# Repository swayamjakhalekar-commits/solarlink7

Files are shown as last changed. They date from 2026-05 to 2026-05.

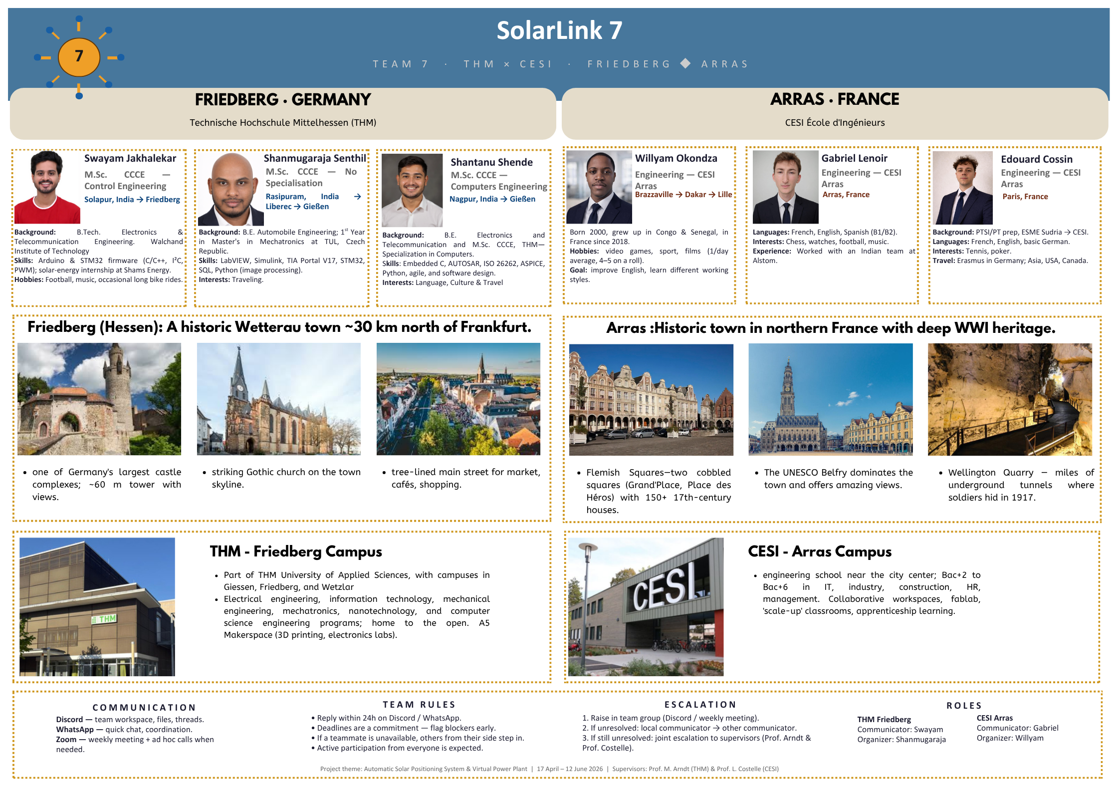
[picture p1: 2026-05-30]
Team and Project/SolarLink7-Poster.png

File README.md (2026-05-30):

# SolarLink7

Automated solar-tracker prototypes at **THM Friedberg (DE)** and **CESI Arras (FR)**,
networked over MQTT into a shared **virtual power plant (VPP)** dashboard. Both sites run
identical prototypes that can be monitored and remote-controlled across one broker.
Built for **COIL 2026 · Course M1202 (Project Management)**.

## Status
Prototypes built and demonstrated at both sites during the project week (27–29 May 2026).
Cross-site MQTT control and the Node-RED VPP dashboard are functioning.
Final presentation: **12 June 2026**.

## Team
| Site | Members |
|---|---|
| THM Friedberg | Swayam Jakhalekar (communicator), Shanmugaraja Senthil (organizer), Shantanu Shende |
| CESI Arras | Gabriel Lenoir (communicator), Willyam Okondza (organizer), Edouard Cossin |
| Supervisors | Prof. Dr. M. Arndt (THM), Prof. L. Costelle (CESI) |

## What it does
Each node reads panel voltage/current via an INA219 sensor, positions the panel with two
servos (automatic maximum-power search, or manual override from the dashboard), shows live values
on a local LCD (THM), and publishes telemetry over MQTT. The Node-RED dashboard shows both
sites side by side and can command either one — that two-site, remote-controllable view is
the VPP demo.

## Repository layout
```
SolarLink7/
├── Arduino Codes/
│   ├── Team7_Friedberg_FinalCode/   # THM firmware
│   ├── Team7_Arras_FinalCode/       # CESI firmware
│   ├── Servos_ZeroPos/              # servo zero/home reference helper
│   └── Servos_MovIndetifier/        # servo direction-of-motion helper
├── 3D_PrintingParts/                # STL parts (base, arm, panel supports, ...)
├── Electronics/                     # Circuit Wiring.png (INA219 + Arduino)
├── Node-Red/                        # Team7_FinalFlow.json + MQTT/Node-RED setup PDF
├── Project Planning and Report/     # WBS, Gantt, competence analysis (PDF)
├── Team and Project/                # brief, poster, team roles/rules/comms plan
├── Measurement/                     # I-V curves, INA219 logs (to be added)
├── Media/                           # photos/video — see Google Drive (not committed)
└── Reflections/                     # weekly reflection journals (to be added)
```

## How tracking works
Tracking is a **two-axis maximum-power search** — measurement-based, not astronomical and
not LDR-based. The panel physically moves and the INA219 power reading (voltage × current)
decides where it settles.

- **Startup:** both servos home, then a full sweep — horizontal 0–180° in 5° steps, then
  vertical, settling 700 ms at each step and recording power. The panel moves to the angle
  that produced the most power. Horizontal is searched first, then vertical.
- **Auto mode:** every 2 minutes the node re-scans only a narrow window around the current
  best (horizontal ±30°, vertical ±20°) rather than a full sweep, so it follows the sun's
  drift without a costly full search each cycle.
- **Manual mode:** a dashboard `control/angle-h|v` command switches the node to manual and
  drives to the requested angle; `control/mode` toggles auto/manual.

Both sites run the identical algorithm; the THM node additionally shows live values on a
16×2 I2C LCD.

## System & MQTT
- **Broker:** `broker.hivemq.com:1883` (public, no auth)
- **Topic base:** `cesithmcoil2025/Team7/<SITE>/` where `<SITE>` is `Friedberg` or `Arras`
- **Telemetry:** `panel-voltage`, `panel-current`, `panel-power`, `position/angle-h`,
  `position/angle-v`, `status`
- **Control:** `control/mode`, `control/angle-h`, `control/angle-v`

The dashboard subscribes to each site's `…/#` wildcard, splits the stream per site, and
routes each field to a widget; control widgets publish back on the `control/...` topics.
See `Node-Red/` for the flow export and setup walkthrough.

## Stack
- **Hardware:** Arduino UNO R4 WiFi · INA219 · 2× SG90 servos · 16×2 I2C LCD (THM) · panel 6.4 V / 360 mA
- **Tracking:** two-axis maximum-power search (INA219 power feedback) — no LDRs, no lat/lon
- **Dashboard:** Node-RED
- **CAD:** TinkerCAD → STL

## Links
- Google Drive (deliverables, media): _add link_
- Trello (task board): _add link_

## License / use
Coursework artifact for M1202. Not for redistribution outside the course.

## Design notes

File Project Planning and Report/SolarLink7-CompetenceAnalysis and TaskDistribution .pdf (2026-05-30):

Member | Site | Role | Project Management | CAD / 3D Design | 3D Printing | Hardware Assembly | Firmware (Arduino) | MQTT / IoT | Node-RED / Dashboard | Documentaion
Swayam Jakhalekar | THM | Communicator | X | | | | X | X | X | X
Shanmugaraja Senthil | THM | Organiser | • | X | | X | | | | X
Shantanu Shende | THM | Member | | | X | • | X | X | X | •
Gabriel Lenoir | CESI | Communicator | X | | | | • | X | X | X
Willyam Okondza | CESI | Organiser | • | X | • | X | • | | | •
Edouard Cossin | CESI | Member | | | X | X | | | | X

Legend:

SolarLink 7 — Team Competence Analysis

Competence areas mapped against assigned project workstreams. X = lead competence; • = supporting competence.

X = lead competence • • = supporting competence • blank = not engaged on this workstream

WBS ID | Task | Type | THM Owner | CESI Owner | Notes
1.1 | Planning document & baseline | Cross-site coordination | Swayam | Gabriel | Communicators jointly own document
1.2 | Weekly steering & minutes | Cross-site coordination | Swayam | Gabriel | Thursday 12:00 CET, Google Meet
1.3 | Risk & issue log | Cross-site coordination | Swayam | Gabriel | Living document, GitHub-tracked
1.4 | Report — technical sections | Joint | Shanmugaraja | Edouard | Firmware, electronics, mechanical
1.5 | Report — PM sections | Joint | Swayam | Gabriel | WBS/Gantt retrospective, lessons learned
1.6 | Report — analysis & conclusions | Joint | All THM | All CESI | Whole-team contribution
1.7 | Final report assembly & review | Cross-site coordination | Swayam | Gabriel | Communicators integrate sections
2.1 | Static panel holder — TinkerCAD design | Joint | Shanmugaraja | Willyam | Lead designer: Willyam; handover to THM via GitHub
2.2 | Print static holder — THM | Site-local | Shantanu | — | Local print at THM open.A5 Makerspace
2.3 | Print static holder — CESI | Site-local | — | Edouard | Local print at CESI facility
2.4 | SPP CAD design | Joint | Shanmugaraja | Willyam | Lead designer: Willyam
2.5 | Print SPP brackets — THM | Site-local | Shantanu | — | Local print at THM
2.6 | Print SPP brackets — CESI | Site-local | — | Edouard | Local print at CESI
2.7 | Servo mounting & calibration | Joint | Shanmugaraja | Willyam | Project week
3.1 | BOM & wiring schematic | Joint | Shanmugaraja | Willyam | Single shared schematic for both sites
3.2 | Build & bring-up — THM | Site-local | Shanmugaraja | — | Identical kit, parallel build
3.3 | Build & bring-up — CESI | Site-local | — | Willyam | Identical kit, parallel build
3.4 | INA219 calibration | Joint | Swayam | Gabriel | Cross-validate with multimeter
3.5 | Sensor + servo firmware | Joint | Swayam | Gabriel | Lead: Swayam; handover to Gabriel
3.6 | Tracking algorithm | Joint | Swayam | Gabriel | Lead: Swayam; time-based, NTP + sun position
3.7 | Local LCD display | Joint | Shanmugaraja | Willyam | Optional; voltage/current/power output
4.1 | MQTT topic schema (cesithmcoil2025/) | Joint | Swayam | Gabriel | Co-designed by communicators
4.2 | MQTT client on Arduino | Joint | Shantanu | Willyam | Setup lead: Shantanu; CESI support
4.3 | Node-RED ingest flow | Joint | Shantanu | Edouard | Setup lead: Shantanu
4.4 | Node-RED VPP dashboard | Joint | Shantanu | Edouard | Setup lead: Shantanu
4.5 | Remote-command handler | Joint | Shantanu | Edouard | End-to-end bidirectional control
5.1 | Site-local end-to-end test | Site-local | All THM | All CESI | Each site validates own prototype
5.2 | Cross-site MQTT test | Cross-site coordination | All THM | All CESI | Both sites publish simultaneously
5.3 | IV-curve measurements | Site-local | All THM | All CESI | Multimeter-based; 27 May project week
5.4 | MPP + optimal load resistor | Site-local | All THM | All CESI | Derived from IV-curve data
5.5 | 30-min energy measurement | Site-local | All THM | All CESI | Fixed tilt, optimal load
5.6 | Project week integration | Cross-site coordination | All THM | All CESI | 27–29 May, joint working window

## SolarLink 7 — Distribution of Tasks Between Locations

Mapping of project tasks to ownership type and location. Site-local = single-site task; Joint = co-owned cross-site; Cross-site coordination = communicator-led bridging task.

Site-local tasks | 10
Joint tasks | 16
Cross-site coordination tasks | 6
Total tasks | 32

## SUMMARY

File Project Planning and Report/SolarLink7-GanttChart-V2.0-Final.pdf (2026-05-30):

Task | Assigned (THM) Assigned (CESI) Progress (%) | Start | End | Status | Days Off

26-04

27-04

28-04

29-04

30-04

01-05

02-05

03-05

04-05

05-05

06-05

07-05

08-05

09-05

10-05

11-05

12-05

13-05

14-05

15-05

16-05

17-05

18-05

19-05

20-05

21-05

22-05

23-05

24-05

25-05

26-05

27-05

28-05

29-05

30-05

31-05

01-06

02-06

03-06

04-06

05-06

06-06

07-06

08-06

09-06

10-06

11-06

12-06

Project Management | | | 0
Planning document & baseline | THM Group | CESI Group | 90% | 2026-04-26 | 2026-05-18 | In Progress | 0
Weekly steering & minutes (Every week group meeting) | Swayam | Gabriel | 30% | 2026-04-29 | 2026-06-12 | In Progress | 0
Risk & issue log | THM Group | CESI Group | 5% | 2026-05-08 | 2026-06-12 | In Progress | 0
Report — technical sections | Shanmugaraja | Edouard | 0% | 2026-05-30 | 2026-06-05 | Upcoming | 0
Report — PM sections | Swayam | Gabriel | 0% | 2026-05-30 | 2026-06-05 | Upcoming | 0
Report — analysis & conclusions | THM Group | CESI Group | 0% | 2026-06-01 | 2026-06-08 | Upcoming | 0
Final report assembly & review | Swayam | Gabriel | 0% | 2026-06-09 | 2026-06-11 | Upcoming | 0
Mechanical Subsystem | | | 0
Static panel holder — TinkerCAD design (joint) | Shanmugaraja | Willyam | 0% | 2026-05-21 | 2026-05-21 | Upcoming | 0
Print static holder — THM | Shantanu | | 0% | 2026-05-21 | 2026-05-21 | Upcoming | 0
Print static holder — CESI | | Edouard | 0% | 2026-05-21 | 2026-05-21 | Upcoming | 0
SPP CAD design (joint) | Shanmugaraja | Willyam | 0% | 2026-05-22 | 2026-05-22 | Upcoming | 0
Print SPP brackets — THM | Shantanu | | 0% | 2026-05-22 | 2026-05-22 | Upcoming | 0
Print SPP brackets — CESI | | Edouard | 0% | 2026-05-22 | 2026-05-22 | Upcoming | 0
Servo mounting & calibration | Shanmugaraja | Willyam | 0% | 2026-05-23 | 2026-05-23 | Upcoming | 0
Electronics & Firmware | | | 0
BOM & wiring schematic | Shanmugaraja | Willyam | 0% | 2026-05-24 | 2026-05-25 | Upcoming | 0
Build & bring-up — THM | Shanmugaraja | | 0% | 2026-05-26 | 2026-05-26 | Upcoming | 0
Build & bring-up — CESI | | Willyam | 0% | 2026-05-26 | 2026-05-26 | Upcoming | 0
INA219 calibration | Swayam | Gabriel | 0% | 2026-05-27 | 2026-05-27 | Upcoming | 0
Sensor + servo | Swayam | Gabriel | 0% | 2026-05-26 | 2026-05-26 | Upcoming | 0
Tracking algorithm | Swayam | Gabriel | 0% | 2026-05-27 | 2026-05-27 | Upcoming | 0
Local LCD display (voltage/current/power output) | Shanmugaraja | Willyam | 0% | 2026-05-27 | 2026-05-27 | Upcoming | 0
MQTT & Dashboard | | | 0
Topic schema under cesithmcoil2025/ | Swayam | Gabriel | 0% | 2026-05-14 | 2026-05-17 | In Progress | 0
MQTT client on Arduino | Shantanu | Willyam | 0% | 2026-05-17 | 2026-05-20 | Upcoming | 0
Node-RED ingest flow | Shantanu | Edouard | 0% | 2026-05-27 | 2026-05-27 | Upcoming | 0
Node-RED VPP dashboard | Shantanu | Edouard | 0% | 2026-05-28 | 2026-05-28 | Upcoming | 0
Remote-command handler | Shantanu | Edouard | 0% | 2026-05-28 | 2026-05-29 | Upcoming | 0
Integration, Test & Deliverables | | | 0
Site-local end-to-end test | THM Group | CESI Group | 0% | 2026-05-29 | 2026-05-29 | Upcoming | 0
Cross-site MQTT test | THM Group | CESI Group | 0% | 2026-05-29 | 2026-05-29 | Upcoming | 0
IV-curve measurements | THM Group | CESI Group | 0% | 2026-05-27 | 2026-05-27 | Upcoming | 0
MPP + optimal load resistor derivation | THM Group | CESI Group | 0% | 2026-05-27 | 2026-05-27 | Upcoming | 0
30-min energy measurement | THM Group | CESI Group | 0% | 2026-05-27 | 2026-05-27 | Upcoming | 0
Project week integration | THM Group | CESI Group | 0% | 2026-05-25 | 2026-05-29 | Upcoming | 0

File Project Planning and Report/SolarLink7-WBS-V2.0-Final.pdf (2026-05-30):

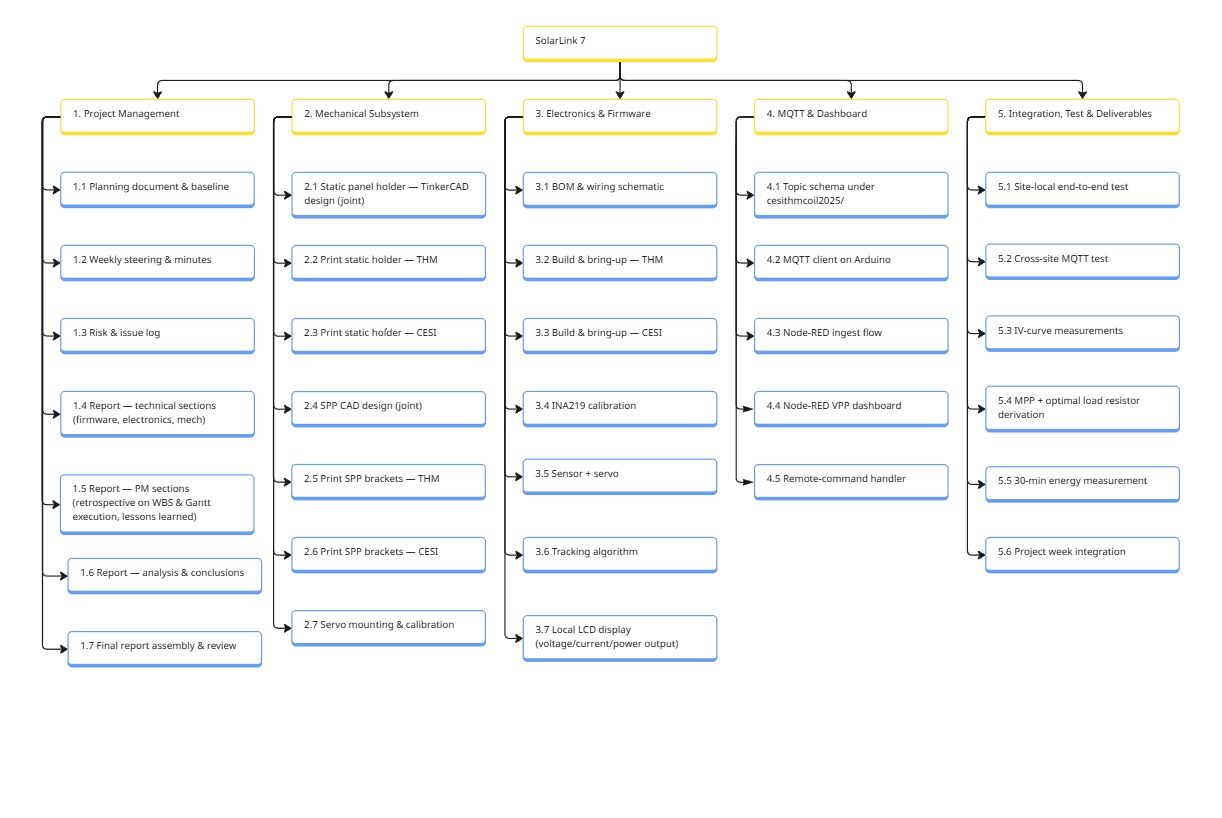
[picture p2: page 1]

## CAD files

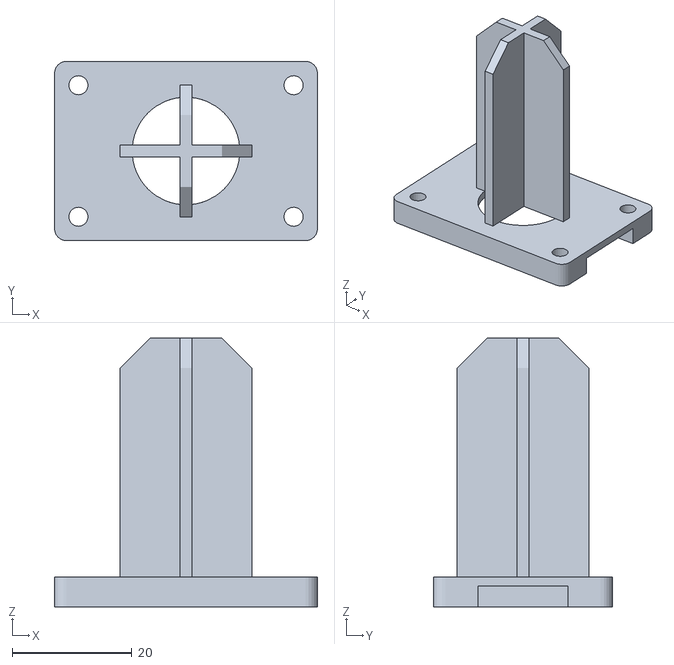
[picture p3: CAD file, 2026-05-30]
3D_PrintingParts/LDR.stl
44.0 x 30.0 x 45.0

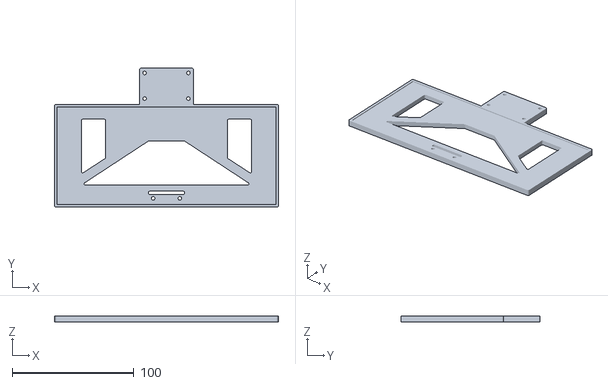
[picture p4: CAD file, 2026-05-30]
3D_PrintingParts/PanelSupport(L).stl
184.0 x 114.0 x 5.00

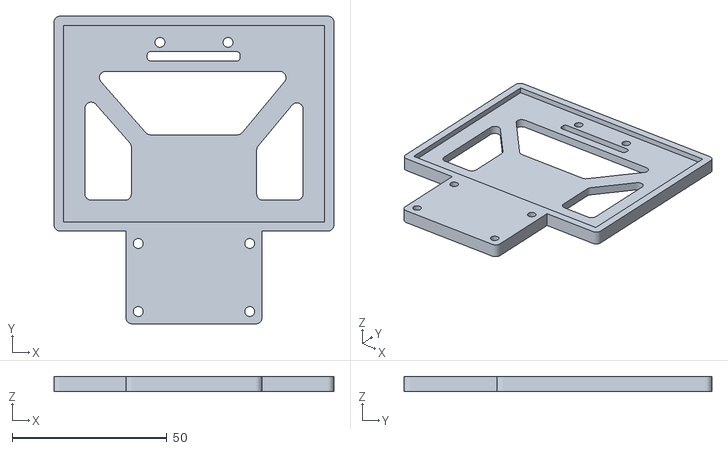
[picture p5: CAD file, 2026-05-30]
3D_PrintingParts/PanelSupport(S).stl
90.5 x 99.5 x 5.00

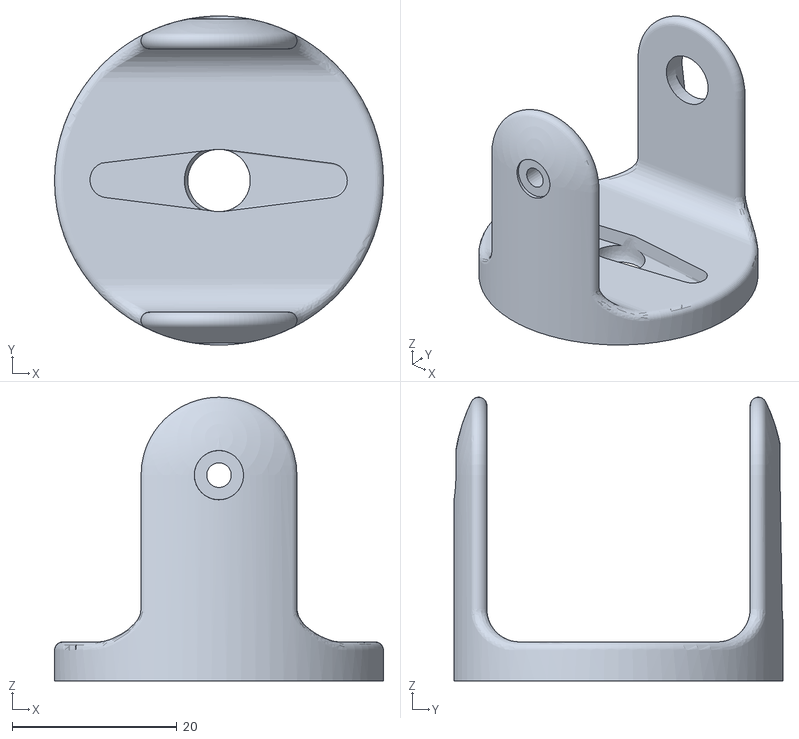
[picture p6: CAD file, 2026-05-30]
3D_PrintingParts/Middle2.0.stl
40.0 x 40.0 x 34.5

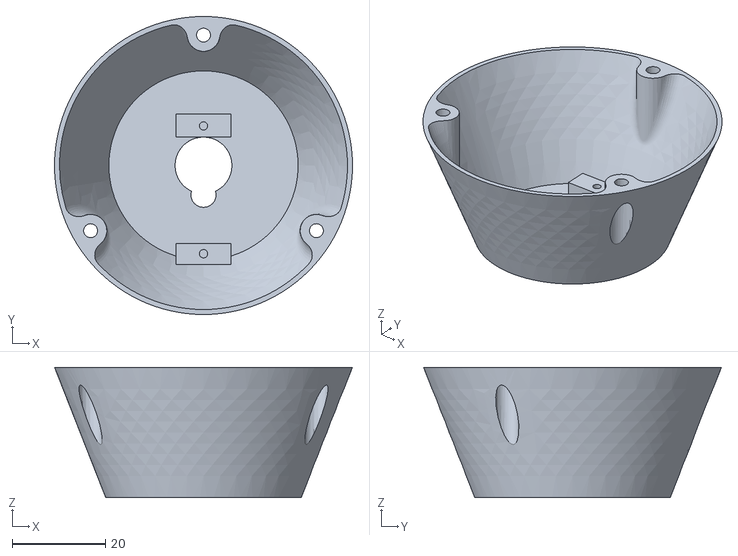
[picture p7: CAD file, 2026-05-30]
3D_PrintingParts/OrgBase.stl
64.0 x 64.0 x 28.0

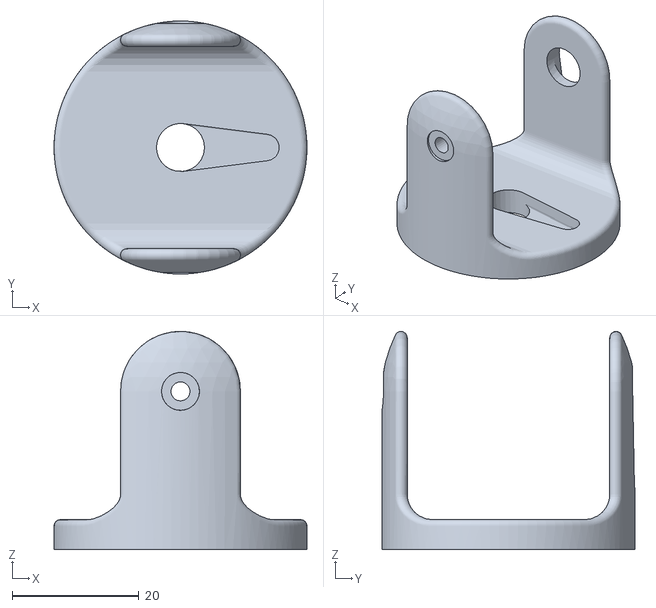
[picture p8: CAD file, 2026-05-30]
3D_PrintingParts/OrgMiddle.stl
40.0 x 40.0 x 34.5

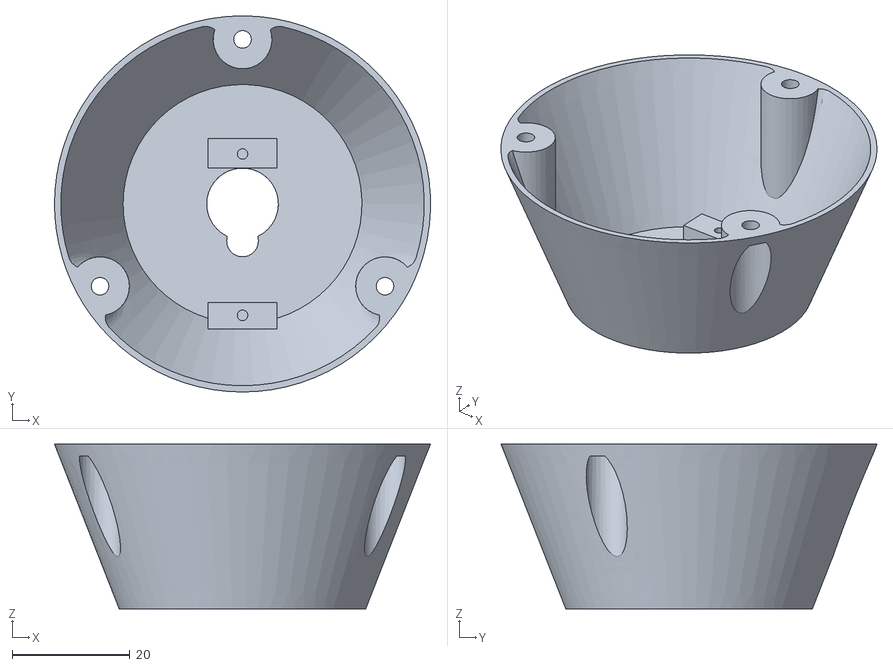
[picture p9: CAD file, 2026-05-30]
3D_PrintingParts/Base2.0.stl
64.0 x 64.0 x 28.0

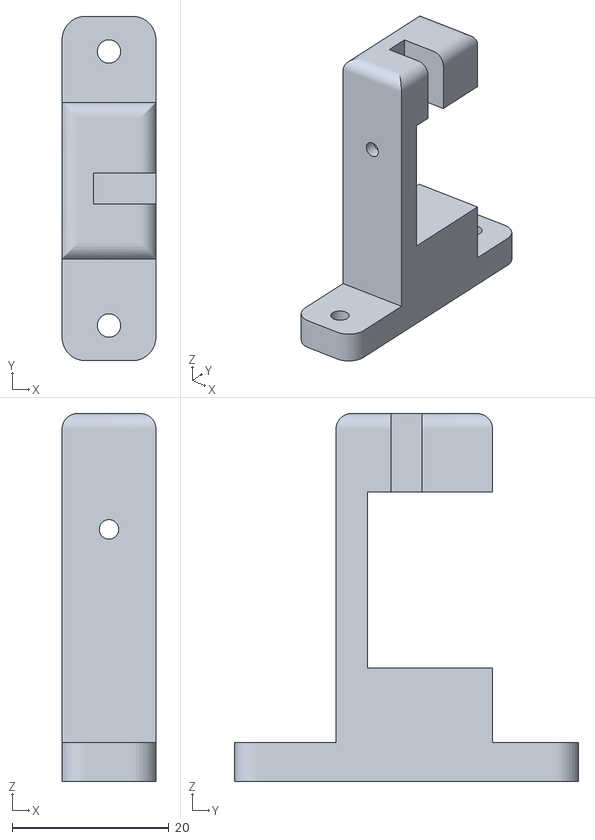
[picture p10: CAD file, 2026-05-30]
3D_PrintingParts/ActualArm.stl
12.0 x 44.0 x 47.0

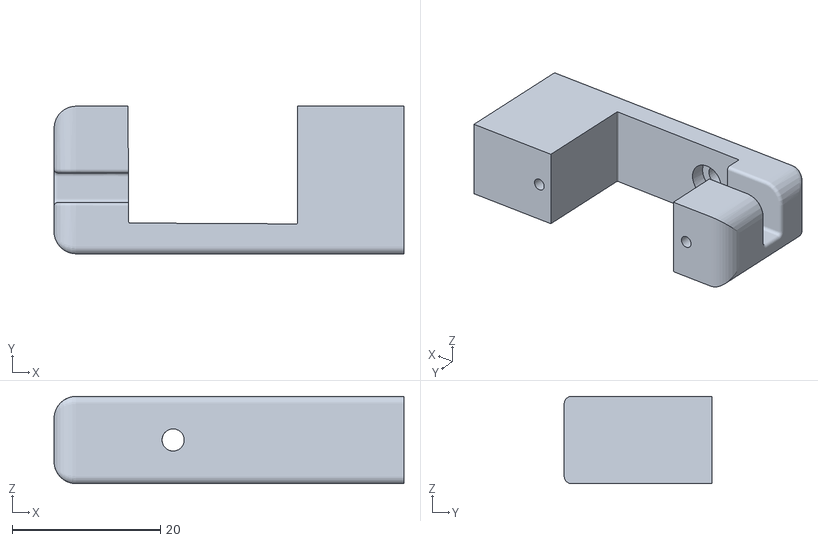
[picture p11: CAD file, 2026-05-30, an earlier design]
3D_PrintingParts/OldArm.stl
47.3 x 19.9 x 11.8

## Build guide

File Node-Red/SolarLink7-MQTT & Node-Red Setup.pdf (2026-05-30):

MQTT and Node-Red Setups Document

Project: Connected Solar Tracker using IoT (MQTT + Node-RED) Team: SolarLink7 (THM / ARRAS)

### 1. Software Used

Software | Purpose | Link
MQTT Explorer | Monitoring MQTT messages | https://mqtt-explorer.com/
Node js | To install Node-Red to work | https://nodejs.org/en/download
Node - Red | Dashboard and Visualization | Node-RED

### 2. MQTT Configuration

Click on (+) and add new connections with following parameters.
Name: Hive
Host: Broker: broker.hivemq.com
Port: 1883

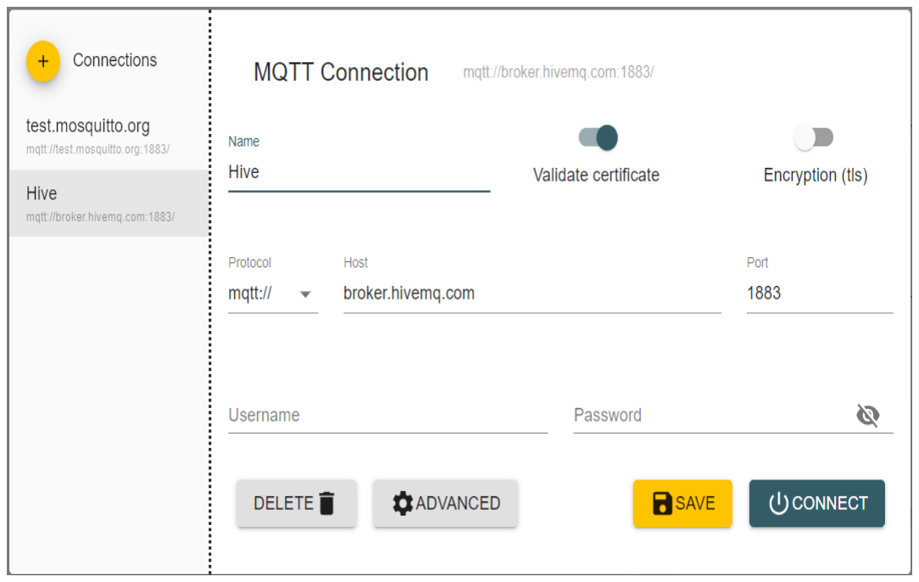
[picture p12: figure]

Then click on Advanced

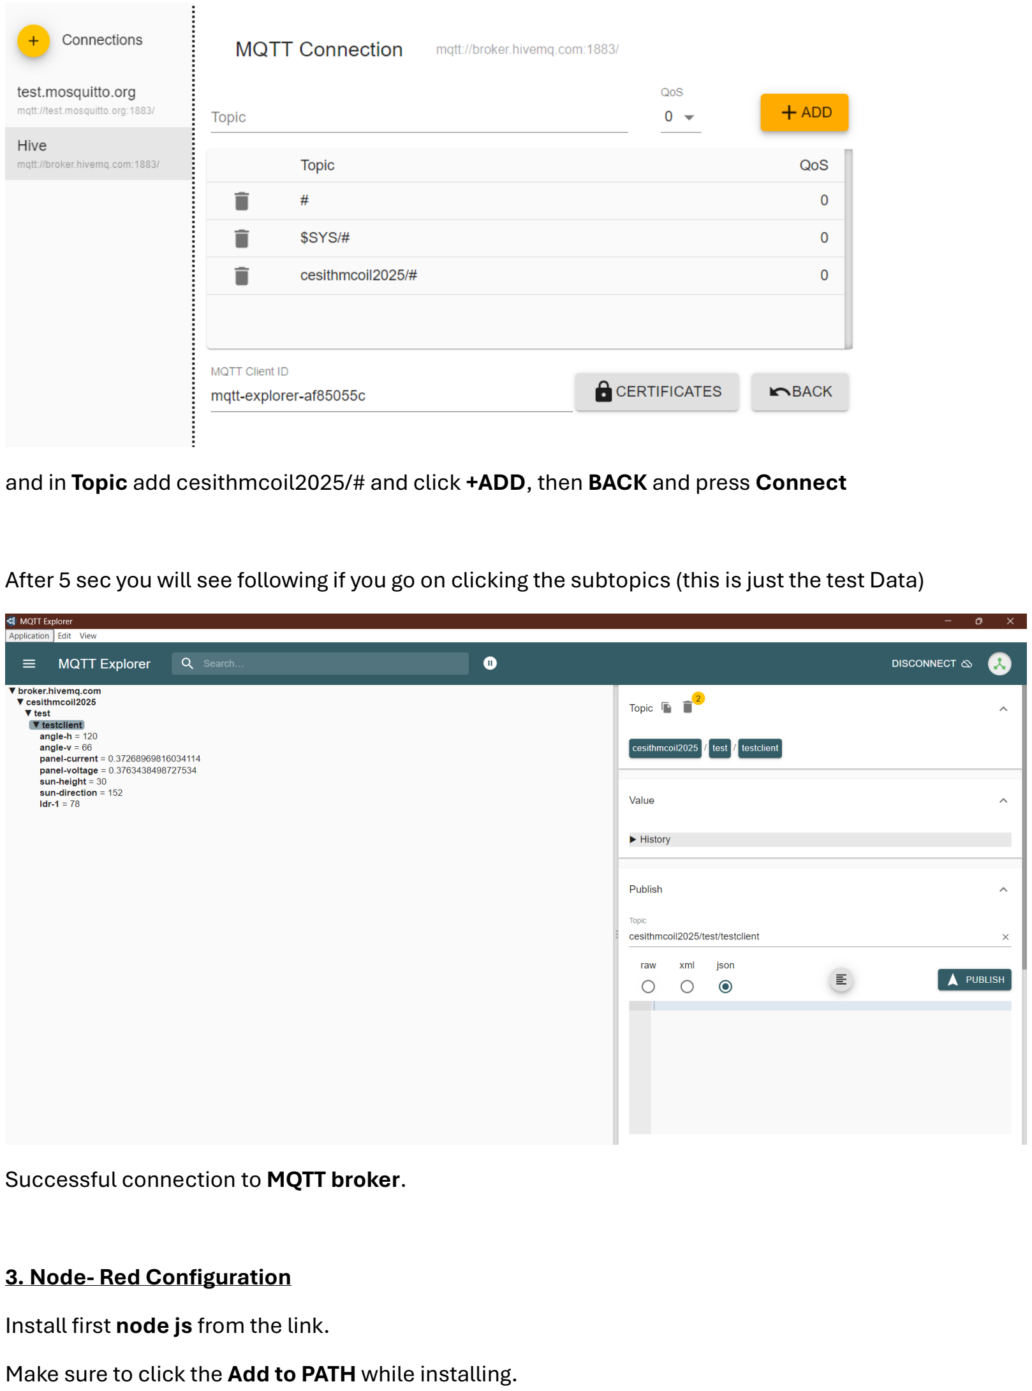
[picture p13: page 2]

and in Topic add cesithmcoil2025/# and click +ADD, then BACK and press Connect

After 5 sec you will see following if you go on clicking the subtopics (this is just the test Data)

Successful connection to MQTT broker.

### 3. Node- Red Configuration

Install first node js from the link.
Make sure to click the Add to PATH while installing.

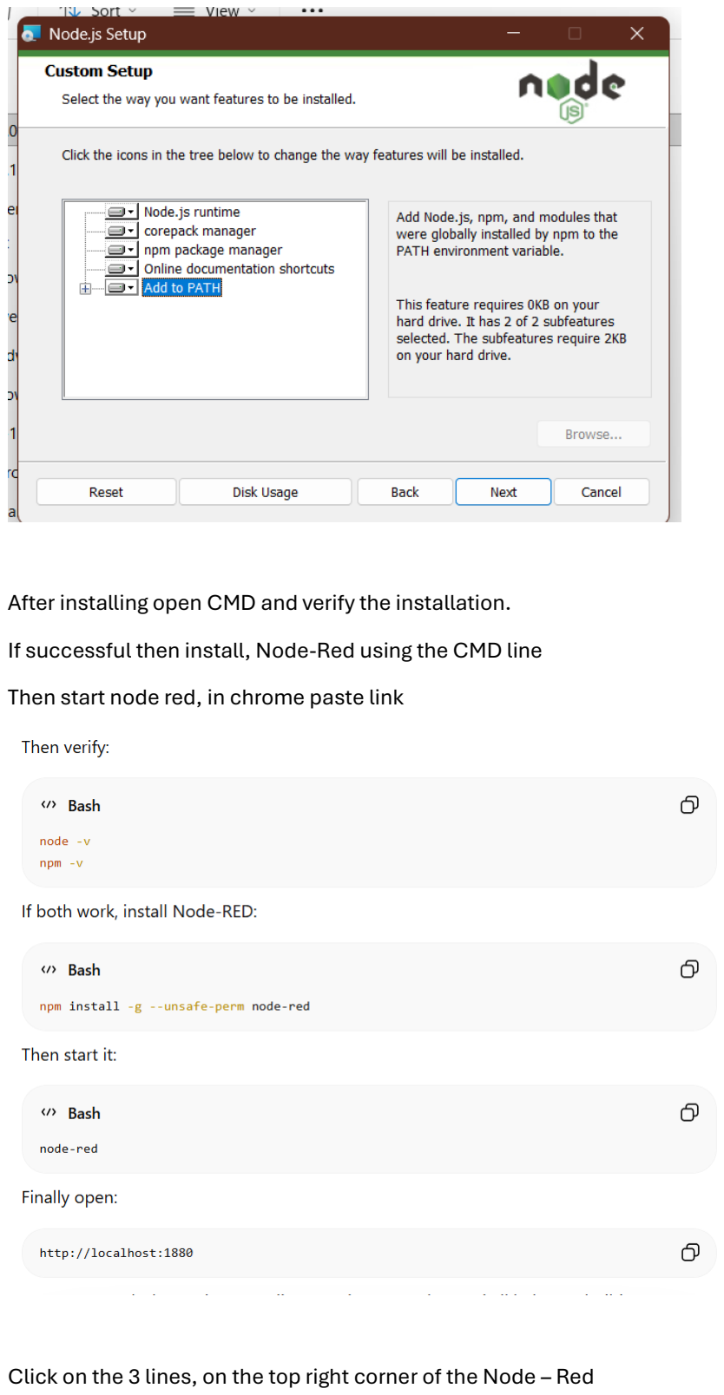
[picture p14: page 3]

After installing open CMD and verify the installation. If successful then install, Node-Red using the CMD line Then start node red, in chrome paste link

Click on the 3 lines, on the top right corner of the Node – Red

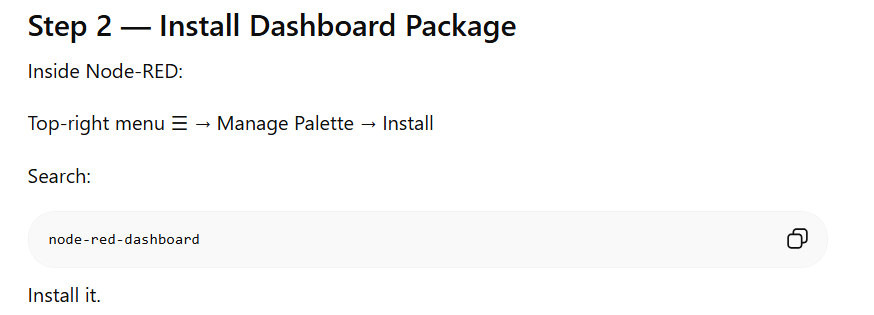
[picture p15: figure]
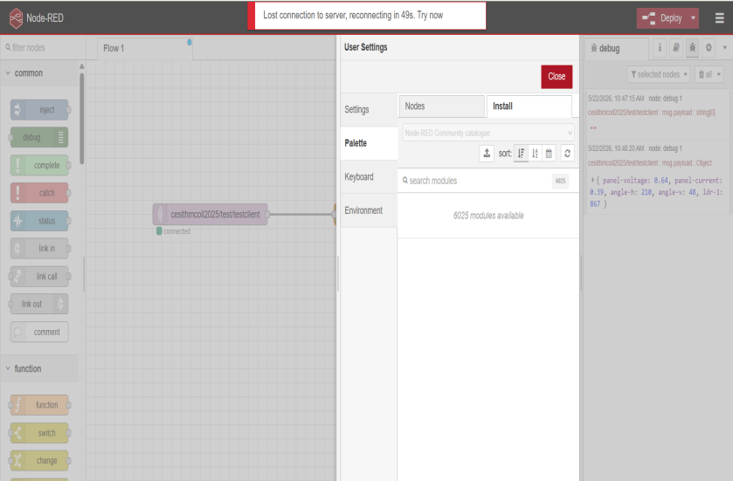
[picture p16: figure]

Then build Flow for the Team .

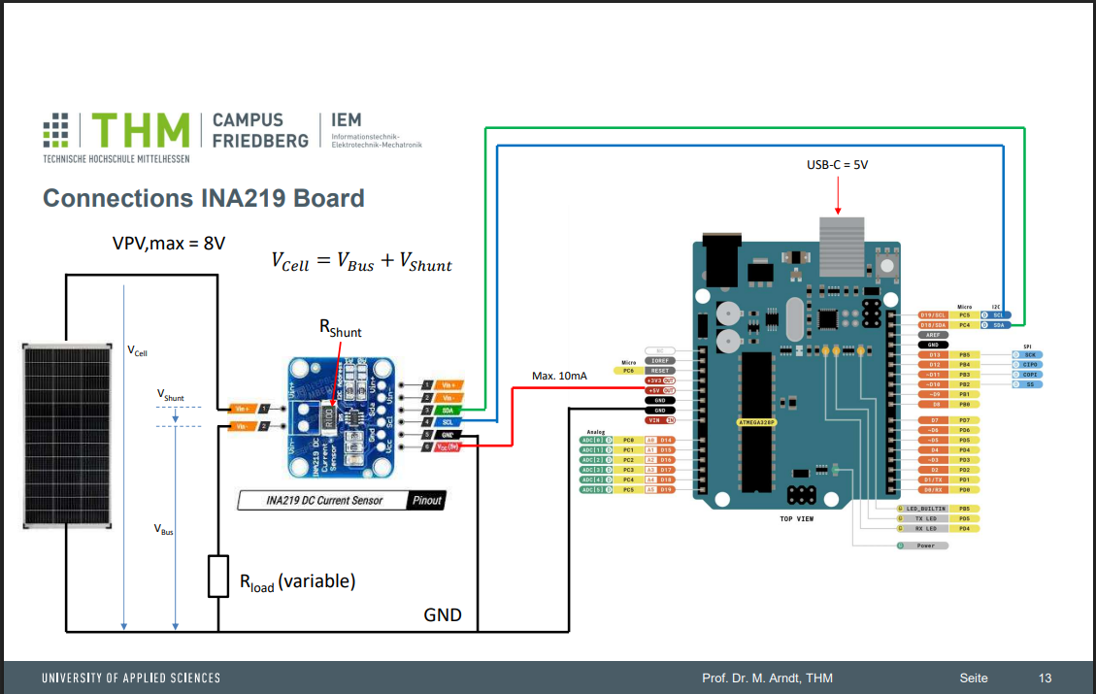
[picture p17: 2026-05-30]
Electronics/Circuit Wiring.png

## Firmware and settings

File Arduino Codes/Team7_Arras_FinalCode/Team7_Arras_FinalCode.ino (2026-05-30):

// ======================================================
// TEAM7 FINAL SOLAR TRACKER
// ARRAS FINAL VERSION
// ======================================================

#include <Wire.h>
#include <WiFiS3.h>
#include <PubSubClient.h>
#include <Adafruit_INA219.h>
#include <Servo.h>

// ======================================================
// WIFI
// ======================================================

char ssid[] = //"YOUR SSID";
char pass[] = //"YOUR PASSWORD";

// ======================================================
// MQTT
// ======================================================

const char* mqtt_server =
"broker.hivemq.com";

WiFiClient wifiClient;

PubSubClient client(wifiClient);

// ======================================================
// COMPONENTS
// ======================================================

Adafruit_INA219 ina219;

Servo servoH;
Servo servoV;

// ======================================================
// SERVO PINS
// ======================================================

const int SERVO_H_PIN = 9;
const int SERVO_V_PIN = 10;

// ======================================================
// SERVO SETTINGS
// ======================================================

const int CENTER_V = 90;

// smoother movement

const int STEP_DELAY_MIN = 15;
const int STEP_DELAY_MAX = 45;

const int EASE_FRACTION  = 35;

const int SETTLE = 700;

// ======================================================
// HOMING SETTINGS
// ======================================================

// smoother homing

const int HOME_STEP_DEG = 5;
const int HOME_STEP_MS  = 50;

// ======================================================
// SCAN SETTINGS
// ======================================================

// smoother scanning

const int H_SCAN_STEP = 5;
const int V_SCAN_STEP = 5;

const int H_RESCAN_MARGIN = 30;
const int V_RESCAN_MARGIN = 20;

const unsigned long SCAN_INTERVAL =
120000UL;

unsigned long lastScanTime = 0;

// ======================================================
// POSITION VARIABLES
// ======================================================

int currentH = 90;

// INTERNAL RANGE = -50 → +50

int currentV = 0;

// ======================================================
// POWER VARIABLES
// ======================================================

float voltage    = 0;
float current_mA = 0;
float power_mW   = 0;

// ======================================================
// MODE
// ======================================================

bool manualMode = false;

// ======================================================
// MQTT TOPICS
// ======================================================

const char* topic_h_angle =
"cesithmcoil2025/Team7/Arras/position/angle-h";

const char* topic_v_angle =
"cesithmcoil2025/Team7/Arras/position/angle-v";

const char* topic_voltage =
"cesithmcoil2025/Team7/Arras/panel-voltage";

const char* topic_current =
"cesithmcoil2025/Team7/Arras/panel-current";

const char* topic_power =
"cesithmcoil2025/Team7/Arras/panel-power";

const char* topic_status =
"cesithmcoil2025/Team7/Arras/status";

const char* control_h =
"cesithmcoil2025/Team7/Arras/control/angle-h";

const char* control_v =
"cesithmcoil2025/Team7/Arras/control/angle-v";

const char* control_mode =
"cesithmcoil2025/Team7/Arras/control/mode";

// ======================================================
// EASING
// ======================================================

int easeDelay(int moved, int total) {

  if (total == 0)
    return STEP_DELAY_MIN;

  int easeSteps =
    max(1,
    (total * EASE_FRACTION) / 100);

  int remaining = total - moved;

  if (moved < easeSteps) {

    return STEP_DELAY_MAX -
      ((STEP_DELAY_MAX -
      STEP_DELAY_MIN)
      * moved / easeSteps);
  }

  if (remaining < easeSteps) {

    return STEP_DELAY_MIN +
      ((STEP_DELAY_MAX -
      STEP_DELAY_MIN)
      * (easeSteps - remaining)
      / easeSteps);
  }

  return STEP_DELAY_MIN;
}

// ======================================================
// MOVE HORIZONTAL
// ======================================================

void moveH(int target) {

  target = constrain(target, 0, 180);

  if (target == currentH)
    return;

  int total =
    abs(target - currentH);

  int step =
    (target > currentH)
    ? 1 : -1;

  int moved = 0;

  while (currentH != target) {

    currentH += step;

    servoH.write(currentH);

    delay(
      easeDelay(moved++, total)
    );
  }
}

// ======================================================
// MOVE VERTICAL
// ======================================================

void moveV(int target) {

  target = constrain(target, -50, 50);

  if (target == currentV)
    return;

  int total =
    abs(target - currentV);

  int step =
    (target > currentV)
    ? 1 : -1;

  int moved = 0;

  while (currentV != target) {

    currentV += step;

    servoV.write(
      CENTER_V + currentV
    );

    delay(
      easeDelay(moved++, total)
    );
  }
}

// ======================================================
// SAFE HOME HORIZONTAL
// ======================================================

void safeHomeH() {

  Serial.println("Homing Horizontal Servo...");

  servoH.write(90);

  delay(500);

  for (int h = 90; h >= 0; h -= HOME_STEP_DEG) {

    servoH.write(h);

    Serial.print("H Position: ");
    Serial.println(h);

    delay(HOME_STEP_MS);
  }

  servoH.write(0);

  delay(300);

  currentH = 0;

  Serial.println("Horizontal Homing Complete");

  delay(700);
}

// ======================================================
// SAFE HOME VERTICAL
// ======================================================

void safeHomeV() {

  Serial.println("Homing Vertical Servo...");

  // stabilize at center first

  servoV.write(CENTER_V);

  delay(700);

  // smooth downward sweep

  for (int v = 0; v >= -50; v -= HOME_STEP_DEG) {

    servoV.write(CENTER_V + v);

    Serial.print("V Position: ");
    Serial.println(v + 50);

    delay(HOME_STEP_MS);
  }

  servoV.write(CENTER_V - 50);

  delay(300);

  currentV = -50;

  Serial.println("Vertical Homing Complete");

  delay(700);
}

// ======================================================
// POWER MEASUREMENT
// ======================================================

void measurePower() {

  voltage =
    ina219.getBusVoltage_V();

  current_mA =
    ina219.getCurrent_mA();

  power_mW =
    voltage * current_mA;
}

// ======================================================
// SERIAL MONITOR UPDATE
// ======================================================

void serialMonitorUpdate() {

  Serial.println("======================");

  Serial.print("MODE: ");

  Serial.println(
    manualMode ?
    "MANUAL" :
    "AUTO"
  );

  Serial.print("H-Angle: ");
  Serial.println(currentH);

  Serial.print("V-Angle: ");
  Serial.println(currentV + 50);

  Serial.print("Voltage: ");
  Serial.print(voltage);
  Serial.println(" V");

  Serial.print("Current: ");
  Serial.print(current_mA);
  Serial.println(" mA");

  Serial.print("Power: ");
  Serial.print(power_mW);
  Serial.println(" mW");

  Serial.println("======================");
}

// ======================================================
// MQTT PUBLISH
// ======================================================

void publishData() {

  client.publish(
    topic_h_angle,
    String(currentH).c_str()
  );

  client.publish(
    topic_v_angle,
    String(currentV + 50).c_str()
  );

  client.publish(
    topic_voltage,
    String(voltage, 2).c_str()
  );

  client.publish(
    topic_current,
    String(current_mA, 2).c_str()
  );

  client.publish(
    topic_power,
    String(power_mW, 2).c_str()
  );

  client.publish(
    topic_status,
    manualMode ?
    "MANUAL MODE" :
    "AUTO MODE"
  );

  serialMonitorUpdate();
}

// ======================================================
// WIFI CONNECTION (DHCP FIXED)
// ======================================================

void connectWiFi() {

  Serial.println("Connecting to WiFi...");

  WiFi.begin(ssid, pass);

  unsigned long start = millis();

  while (WiFi.status() != WL_CONNECTED) {

    delay(500);

    Serial.print(".");

    if (millis() - start > 15000) {

      Serial.println("\nRetrying WiFi...");

      WiFi.disconnect();

      delay(1000);

      WiFi.begin(ssid, pass);

      start = millis();
    }
  }

  while (WiFi.localIP() == IPAddress(0,0,0,0)) {

    Serial.println("Waiting for DHCP...");

    delay(500);
  }

  Serial.println("\nWiFi Connected");

  Serial.print("IP Address: ");
  Serial.println(WiFi.localIP());

  Serial.print("Signal Strength: ");
  Serial.println(WiFi.RSSI());
}

// ======================================================
// MQTT CALLBACK
// ======================================================

void callback(
  char* topic,
  byte* payload,
  unsigned int length
) {

  String message = "";

  for (
    unsigned int i = 0;
    i < length;
    i++
  ) {

    message += (char)payload[i];
  }

  Serial.print("MQTT Message [");
  Serial.print(topic);
  Serial.print("]: ");
  Serial.println(message);

  // MODE

  if (String(topic) == control_mode) {

    if (message == "AUTO")
      manualMode = false;

    if (message == "MANUAL")
      manualMode = true;
  }

  // HORIZONTAL

  if (String(topic) == control_h) {

    manualMode = true;

    moveH(message.toInt());
  }

  // VERTICAL

  if (String(topic) == control_v) {

    manualMode = true;

    int dashboardValue =
      message.toInt();

    int internalAngle =
      dashboardValue - 50;

    moveV(internalAngle);
  }
}

// ======================================================
// MQTT CONNECT
// ======================================================

void connectMQTT() {

  client.setServer(
    mqtt_server,
    1883
  );

  client.setCallback(callback);

  while (!client.connected()) {

    Serial.println("Connecting to MQTT Broker...");

    String clientId =
      "Team7Arras-" +
      String(random(1000, 9999));

    Serial.print("Client ID: ");
    Serial.println(clientId);

    if (client.connect(clientId.c_str())) {

      Serial.println("MQTT Connected");
      Serial.println("Team7 Online");

      client.subscribe(control_h);
      client.subscribe(control_v);
      client.subscribe(control_mode);

      Serial.println("MQTT Topics Subscribed");

    } else {

      Serial.print("MQTT Failed, rc=");
      Serial.println(client.state());

      Serial.println("Retrying in 3 sec...");

      delay(3000);
    }
  }
}

// ======================================================
// HORIZONTAL SCAN
// ======================================================

void scanBestHorizontal(bool fullScan = false) {

  Serial.println("Searching Best Horizontal Angle...");

  int scanMin =
    fullScan ?
    0 :
    max(0, currentH - H_RESCAN_MARGIN);

  int scanMax =
    fullScan ?
    180 :
    min(180, currentH + H_RESCAN_MARGIN);

  float bestPower = -1;

  int bestAngle = currentH;

  for (int angle = scanMin;
       angle <= scanMax;
       angle += H_SCAN_STEP) {

    moveH(angle);

    delay(SETTLE);

    measurePower();

    Serial.print("H Angle: ");
    Serial.print(angle);

    Serial.print(" | Power: ");
    Serial.print(power_mW);
    Serial.println(" mW");

    if (power_mW > bestPower) {

      bestPower = power_mW;

      bestAngle = angle;
    }
  }

  moveH(bestAngle);

  delay(500);
}

// ======================================================
// VERTICAL SCAN
// ======================================================

void scanBestVertical(bool fullScan = false) {

  Serial.println("Searching Best Vertical Angle...");

  int scanMin =
    fullScan ?
    -50 :
    max(-50, currentV - V_RESCAN_MARGIN);

  int scanMax =
    fullScan ?
    50 :
    min(50, currentV + V_RESCAN_MARGIN);

  float bestPower = -1;

  int bestAngle = currentV;

  for (int angle = scanMin;
       angle <= scanMax;
       angle += V_SCAN_STEP) {

    moveV(angle);

    delay(SETTLE);

    measurePower();

    Serial.print("V Angle: ");
    Serial.print(angle + 50);

    Serial.print(" | Power: ");
    Serial.print(power_mW);
    Serial.println(" mW");

    if (power_mW > bestPower) {

      bestPower = power_mW;

      bestAngle = angle;
    }
  }

  moveV(bestAngle);

  delay(500);
}

// ======================================================
// SETUP
// ======================================================

void setup() {

  Serial.begin(115200);

  delay(1000);

  Serial.println("TEAM7 SOLAR TRACKER");
  Serial.println("ARRAS FINAL SMOOTH VERSION");

  randomSeed(millis());

  servoH.attach(SERVO_H_PIN);
  servoV.attach(SERVO_V_PIN);

  delay(700);

  if (!ina219.begin()) {

    Serial.println("INA219 ERROR");

    while(1);
  }

  Serial.println("INA219 Connected");

  safeHomeH();

  safeHomeV();

  connectWiFi();

  connectMQTT();

  scanBestHorizontal(true);

  scanBestVertical(true);

  lastScanTime = millis();
}

// ======================================================
// LOOP
// ======================================================

void loop() {

  if (WiFi.status() != WL_CONNECTED) {

    Serial.println("WiFi Lost!");

    connectWiFi();
  }

  if (!client.connected()) {

    Serial.println("MQTT Lost!");

    connectMQTT();
  }

  client.loop();

  // MANUAL MODE

  if (manualMode) {

    measurePower();

    publishData();

    delay(500);

    return;
  }

  // AUTO MODE

  if (
    millis() - lastScanTime
    >= SCAN_INTERVAL
  ) {

    scanBestHorizontal(false);

    scanBestVertical(false);

    lastScanTime = millis();
  }

  measurePower();

  publishData();

  delay(1000);
}

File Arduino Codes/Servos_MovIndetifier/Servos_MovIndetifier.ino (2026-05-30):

// ======================================================
// SERVO INIT TEST
// Horizontal → 0° then +20° = 20°  (pin 9)
// Vertical   → 90° then +20° = 110° (pin 10)
// ======================================================

#include <Servo.h>

Servo servoH;
Servo servoV;

const int CENTER_V = 90;
int currentV = 0;

void setup() {

  servoH.attach(9);
  servoV.attach(10);

  // Init position
  servoH.write(0);
  servoV.write(CENTER_V + currentV);  // 90 + 0 = 90

  delay(2000);  // Hold init position for 2 seconds

  // Move both by +20 degrees
  currentV = 20;

  servoH.write(20);
  servoV.write(CENTER_V + currentV);  // 90 + 20 = 110

}

void loop() {
  // Hold position — nothing to do
}
